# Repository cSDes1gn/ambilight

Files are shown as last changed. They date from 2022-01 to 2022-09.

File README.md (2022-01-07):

# Hyperion Server Automation



Modified: 2022-01

Hyperion
Hyperion

Ansible automation for setup and teardown of hyperion servers for raspbian lite.

## Quickstart

### Setup
Install ansible
```bash
python3 -m pip install ansible
```

Run the prelink directive passing the hostname and ip address of the pi. On rasbian the default hostname is `pi`. For example:
```bash
./scripts/prelink.sh -u pi -a 192.168.2.19
```
This essentially just adds your host systems public key to the list of authorized keys on the pi which is required to run ansible. 

>By default the script will look in `~/.ssh` for an `id_rsa.pub` file but you can pass a custom ssh keypath with the -p flag:
>```bash
>./scripts/prelink.sh -u $HOSTNAME -a $IP_ADDRESS -p $SSH_KEYPATH
>```

Create an inventory file from the example to describe automation targets:
```bash
cp inventory/example.inventory.yaml inventory/inventory.yaml
```
>Be sure to update the host and target ip.

### Automation
Run hyperion server deployment automation:
```bash
ansible-playbook main.yml -e '{ teardown: False }' -K
```

And teardown:
```bash
ansible-playbook main.yml -e '{ teardown: True }' -K
```

## License
Free to use through the [MIT License](LICENSE)

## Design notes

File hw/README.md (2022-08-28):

# Ambilight Hardware

Ambilight BOM, Power Driver and Enclosure hardware files.

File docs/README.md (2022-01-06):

# Documentation

## Access
Server hosted on
```
http://$PI_IP:8090
```

## Configuration
 - Enable Internet API Access
 - Enable capture card source

## Hyperiond
Hyperion needs to run as root to have access to the PWM interface. Probably could find a more perm solution to this but for now:
```
sudo systemctl disable --now hyperion@pi
sudo systemctl enable --now hyperion@root
```

Got locked out once:
```
sudo systemctl stop hyperion
hyperiond -v --resetPassword
sudo systemctl restart hyperion
...
```
## LED Interface
Uses WS281x PWM inteface (one wire) on GPIO18.

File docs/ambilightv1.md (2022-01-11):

# Hardware Requirements

- [ ] RPi4 Model B
- [ ] Ambilight Driver Board
- [ ] WS218B Individually Addressable LED Strip https://www.amazon.ca/gp/product/B01CDTEJBG/ref=ppx_yo_dt_b_asin_title_o05_s00?ie=UTF8&th=1
- [ ] 20A 5V PSU https://www.amazon.ca/gp/product/B07TZNMD8K/ref=ppx_yo_dt_b_asin_title_o00_s00?ie=UTF8&psc=1
- [ ] HDMI 1080p Capture Card with Linux Driver Support (No Loopback) https://www.amazon.ca/Camcorder-Definition-Acquisition-Broadcasting-Conferences/dp/B08CCYNLG4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
- [ ] 4K HDMI Splitter with HDCP 2.2 support https://www.amazon.ca/dp/B07XCZC6SP?psc=1&smid=AUHL7HYID4S97&ref_=chk_typ_imgToDp

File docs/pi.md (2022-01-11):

# Rasbian Lite Setup

1. Flash rasbian lite using the imager or whatever.

2. Enable ssh
```bash
# /Volumes/boot
touch ssh
```

3. Setup wifi
```bash
touch wpa_supplicant.conf
```

4. Setup wifi in firmware conf using wpa
```
country=US # replace with your country code
ctrl_interface=DIR=/var/run/wpa_supplicant GROUP=netdev
network={
    ssid="WIFI_NETWORK_NAME"
    psk="WIFI_PASSWORD"
    key_mgmt=WPA-PSK
}
```

## Troubleshooting
Here is the raspberrypi computer technical specification:
https://www.raspberrypi.com/documentation/computers/raspberry-pi.html#typical-power-requirements

Main issue is with power. The Pi is constantly experiencing under-voltage errors and causing eratic behaviour. The undervoltage is caused by large current draw from both the capture card and the LED strip. This has been verified using `dmesg`

Based on the RPi4B technical specification the recommended PSU current capacity is 3.0A. This is the highest amperage rating of all other RPi generations. The amperage per LED is roughly modelled by:
```
Am = n * 0.06A
```
Where n is the number of LEDs in the strip. Therefore, the max amperage for 220 LEDs is 13.2A. Factoring in the 3.0A for the pi we get 16.2A which is significantly more than the 10A supply we purchased.

Therefore there are a few options that can be done to mitigate this problem:

- [ ] Add 1000uF bulk decoupling capacitor for the LED strip\
- [ ] Add logic level inverter for PWM signal (3.3 -> 5V)
- [ ] Increase the PSU specification and add voltage regulator for pi
- [ ] Add dual USB 3.0 driver cable to support external power requirements for the capture card
- [ ] Increase the PSU specification

### Power Consumption
You can check how much power is negotiated for the 4K capture card device (`1e4e:7103`) using `lsusb`:
```
pi@raspberrypi:~ $ lsusb -v|egrep "^Bus|MaxPower"
Couldn't open device, some information will be missing
Couldn't open device, some information will be missing
Bus 002 Device 001: ID 1d6b:0003 Linux Foundation 3.0 root hub
    MaxPower                0mA
Bus 001 Device 023: ID 1e4e:7103 Cubeternet 
    MaxPower              150mA
Couldn't open device, some information will be missing
Couldn't open device, some information will be missing
Bus 001 Device 002: ID 2109:3431 VIA Labs, Inc. Hub
    MaxPower              100mA
Bus 001 Device 001: ID 1d6b:0002 Linux Foundation 2.0 root hub
    MaxPower                0mA
```

This is way below the 1.2A USB power budget for the RPi4 Model B. Therefore there is no power compatibility problem between the capture card and the RPi4.

### Capture Card UVC Driver
After some power cycles initiated by the RPi the device appears to be recognized:
```
[ 1242.891130] usb usb2-port1: attempt power cycle
[ 1247.330467] usb usb2-port1: Cannot enable. Maybe the USB cable is bad?
[ 1251.670204] usb usb2-port1: Cannot enable. Maybe the USB cable is bad?
[ 1251.670611] usb usb2-port1: unable to enumerate USB device
[ 1255.989989] usb usb2-port1: Cannot enable. Maybe the USB cable is bad?
[ 1260.529701] usb usb2-port1: Cannot enable. Maybe the USB cable is bad?
[ 1264.869483] usb usb2-port1: Cannot enable. Maybe the USB cable is bad?
[ 1264.869891] usb usb2-port1: attempt power cycle
[ 1269.309203] usb usb2-port1: Cannot enable. Maybe the USB cable is bad?
[ 1271.739284] usb 2-1: new SuperSpeed Gen 1 USB device number 52 using xhci_hcd
[ 1271.777322] usb 2-1: New USB device found, idVendor=1e4e, idProduct=7103, bcdDevice= 1.00
[ 1271.777343] usb 2-1: New USB device strings: Mfr=6, Product=7, SerialNumber=3
[ 1271.777361] usb 2-1: Product: UHA-UTCA
[ 1271.777379] usb 2-1: Manufacturer: UHA-UTCA
[ 1271.777396] usb 2-1: SerialNumber: 20000130041415
[ 1271.781874] usb 2-1: WARN: Max Exit Latency too large
[ 1271.781897] usb 2-1: Could not enable U2 link state, xHCI error -22.
[ 1271.783771] uvcvideo: Found UVC 1.00 device UHA-UTCA (1e4e:7103)
[ 1271.787861] uvcvideo: UVC non compliance - GET_DEF(PROBE) not supported. Enabling workaround.
[ 1273.758892] usb 2-1: USB disconnect, device number 52
[ 1274.109122] usb 2-1: new SuperSpeed Gen 1 USB device number 53 using xhci_hcd
[ 1274.147032] usb 2-1: New USB device found, idVendor=1e4e, idProduct=7103, bcdDevice= 1.00
[ 1274.147053] usb 2-1: New USB device strings: Mfr=6, Product=7, SerialNumber=3
[ 1274.147072] usb 2-1: Product: UHA-UTCA
[ 1274.147089] usb 2-1: Manufacturer: UHA-UTCA
[ 1274.147107] usb 2-1: SerialNumber: 20000130041415
[ 1274.149677] uvcvideo: Found UVC 1.00 device UHA-UTCA (1e4e:7103)
```

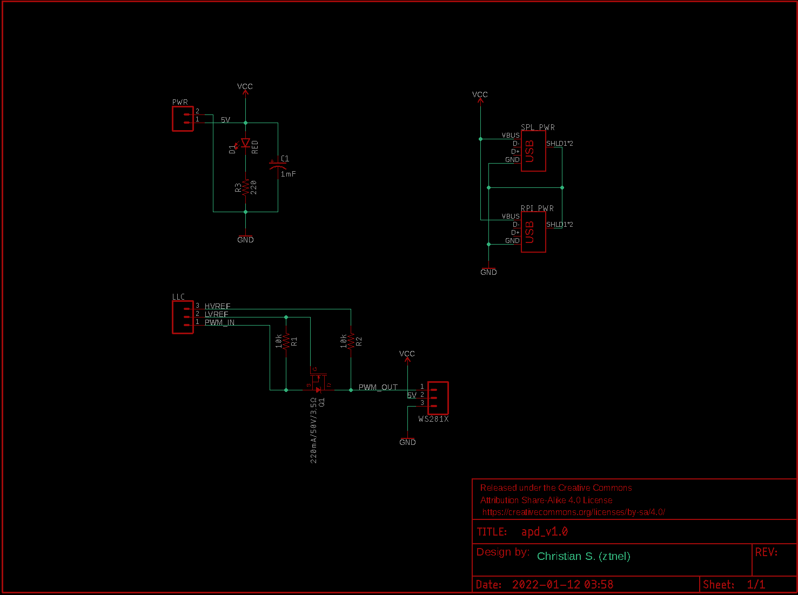
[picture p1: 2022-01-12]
hw/ambilight/apd_v1.0.png

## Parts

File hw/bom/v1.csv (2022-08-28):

Item | Manufacturer | Supplier | Quantity | Unit Price | Net Price
5m 60LEDS/m WS2812B RGB 5050SMD LED Strip | BTF-LIGHTING | Amazon | 1 | CA$50.99 | CA$50.99
5V 20A Switching PSU | Aclorol | Amazon | 1 | CA$24.39 | CA$24.39
RPi 3B/4 Zero | RaspberryPi | Amazon | 1 | CA$60.00 | CA$60.00
HDMI Capture Card USB (MS2109) | - | Amazon | 1 | CA$15.99 | CA$15.99
15A 250V Power Rocker Switch | BZ 3D | Amazon | 1 | CA$11.99 | CA$11.99
12 Pack Hook Loop Tape | EOTW | Amazon | 1 | CA$13.19 | CA$13.19
Heatshrink |  | Amazon |  |  | 0
24 AWG Wire |  | Amazon |  |  | 0
18 AWG Wire |  | Amazon |  |  | 0
2.54mm Dupont Female Crimps |  | Amazon | 5 |  | 0
2.54mm Dupont Female Covers |  | Amazon | 5 |  | 0
1mF Electrolytic Capacitor |  |  | 1 |  | 0
0603 LED |  |  | 1 |  | 0
0603 330R Resistor |  |  | 1 |  | 0
0603 10K Resistor |  |  | 2 |  | 0
BSS138 MOSFET |  | Amazon | 1 |  | 0
USB 2.0 Female SMD Connector |  | Amazon | 2 |  | 0
JST .54mm JST-XH 3 Pin Male Connectors |  | Amazon | 2 |  | 0
JST .54mm JST-XH 3 Pin Female Connectors |  | Amazon | 2 |  | 0
APDv1 PCB | JLCPCB | JLCPCB | 1 | CA$3.07 | CA$3.07
System Enclosure | - | - | 1 |  | 0
1.8mm APD Standoffs | - | - | 3 |  | 0
3.5mm RPI Standoffs | - | - | 4 |  | 0
M2 8mm Screw | PGMJ | Amazon | 3 |  | 0
M3 8mm Screw | PGMJ | Amazon | 4 |  | 0
M3 16mm Screw | PGMJ | Amazon | 3 |  | 0
 |  |  |  |  | CA$179.62

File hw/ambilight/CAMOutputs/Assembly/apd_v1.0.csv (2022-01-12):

Part | Value | Device | Package | Description | PROD_ID | SF_ID | SF_SKU | VALUE
C1 | 1mF | 1000UF-RADIAL-5MM-25V-20% | CPOL-RADIAL-5MM-10MM | 1,000µF/1mF ceramic capacitors | CAP-09538 |  |  | 1mF
D1 | RED | LED-RED0603 | LED-0603 | Red SMD LED | DIO-00819 |  |  | RED
FRAME1 | FRAME-LETTER | FRAME-LETTER | CREATIVE_COMMONS | Schematic Frame - Letter
LLC |  | CONN_03POLAR | MOLEX-1X3 | Multi connection point. Often used as Generic Header-pin footprint for 0.1 inch spaced/style header connections | CONN-08625 | PRT-08096
PWR |  | CONN_025MM | SCREWTERMINAL-5MM-2 | Multi connection point. Often used as Generic Header-pin footprint for 0.1 inch spaced/style header connections |  |  | PRT-08432
Q1 | 220mA/50V/3.5Ω | MOSFET-NCH-BSS138 | SOT23-3 | N-channel MOSFETs | TRANS-00830 |  |  | 220mA/50V/3.5Ω
R1 | 10k | 10KOHM-0603-1/10W-1% | 0603 | 10kΩ resistor | RES-00824 |  |  | 10k
R2 | 10k | 10KOHM-0603-1/10W-1% | 0603 | 10kΩ resistor | RES-00824 |  |  | 10k
R3 | 220 | 220OHM-0603-1/10W-1% | 0603 | 220Ω resistor | RES-07861 |  |  | 220
RPI_PWR | USB_A_SMT_FEMALE | USB_A_SMT_FEMALE | USB-A-S-SILK-FEMALE | USB-A Connector | CONN-09520 | PRT-09011
SPL_PWR | USB_A_SMT_FEMALE | USB_A_SMT_FEMALE | USB-A-S-SILK-FEMALE | USB-A Connector | CONN-09520 | PRT-09011
WS281X |  | CONN_03POLAR | MOLEX-1X3 | Multi connection point. Often used as Generic Header-pin footprint for 0.1 inch spaced/style header connections | CONN-08625 | PRT-08096

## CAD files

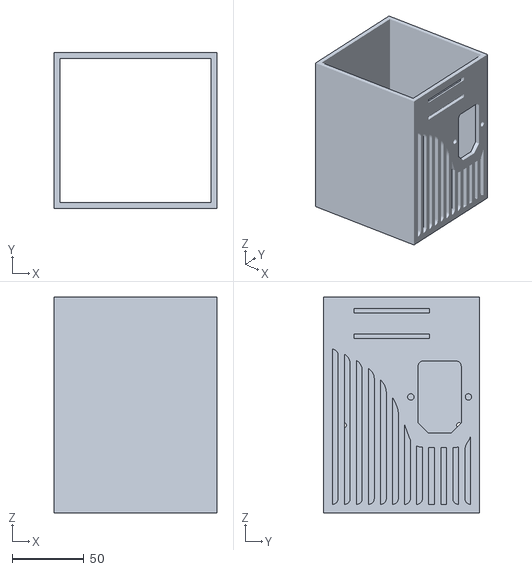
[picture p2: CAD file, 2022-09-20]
hw/fusion/Ambilight Beta v7.stl
113.0 x 108.0 x 150.0

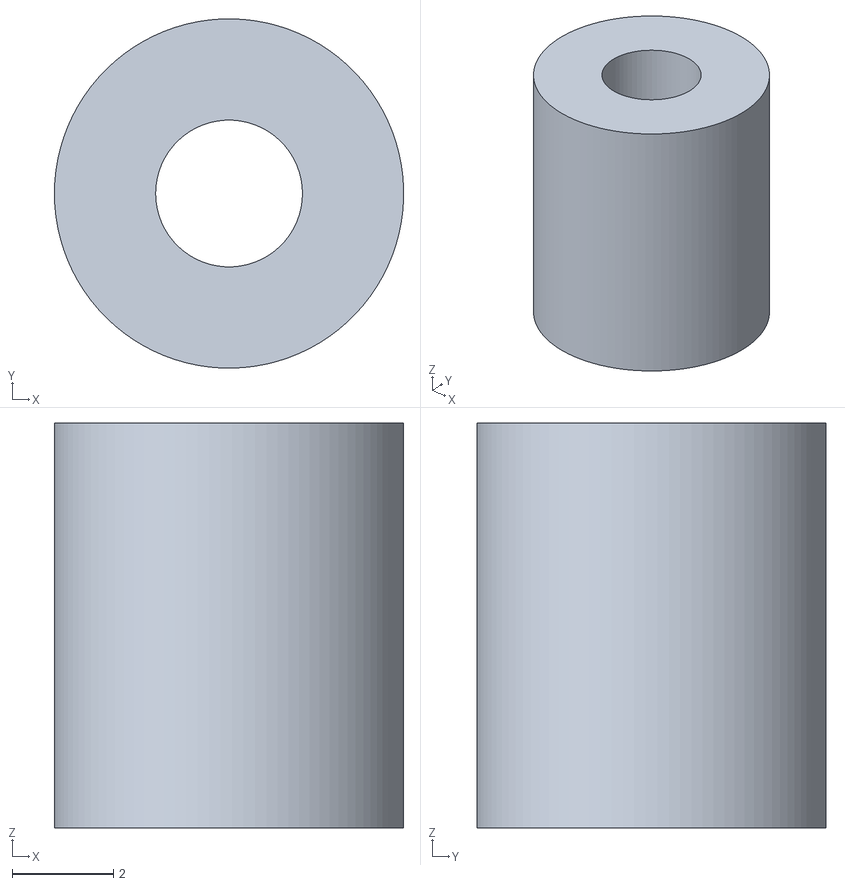
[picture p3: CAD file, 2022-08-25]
hw/fusion/rpi_standoff.stl
6.90 x 6.90 x 8.00

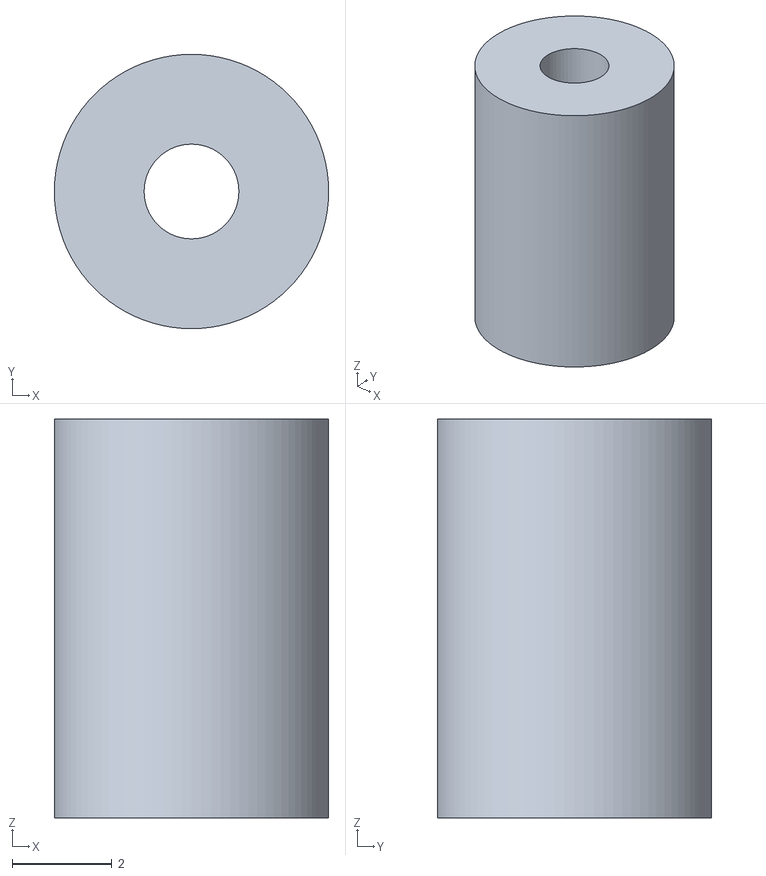
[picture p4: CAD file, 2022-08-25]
hw/fusion/apd_standoff.stl
5.50 x 5.50 x 8.00

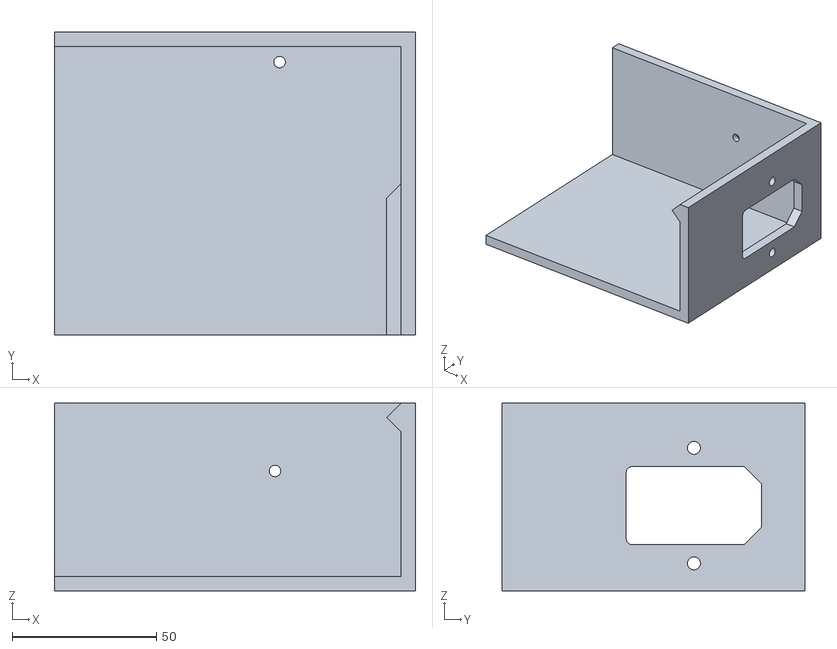
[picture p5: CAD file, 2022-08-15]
hw/fusion/Quad2.stl
125.0 x 105.0 x 65.0

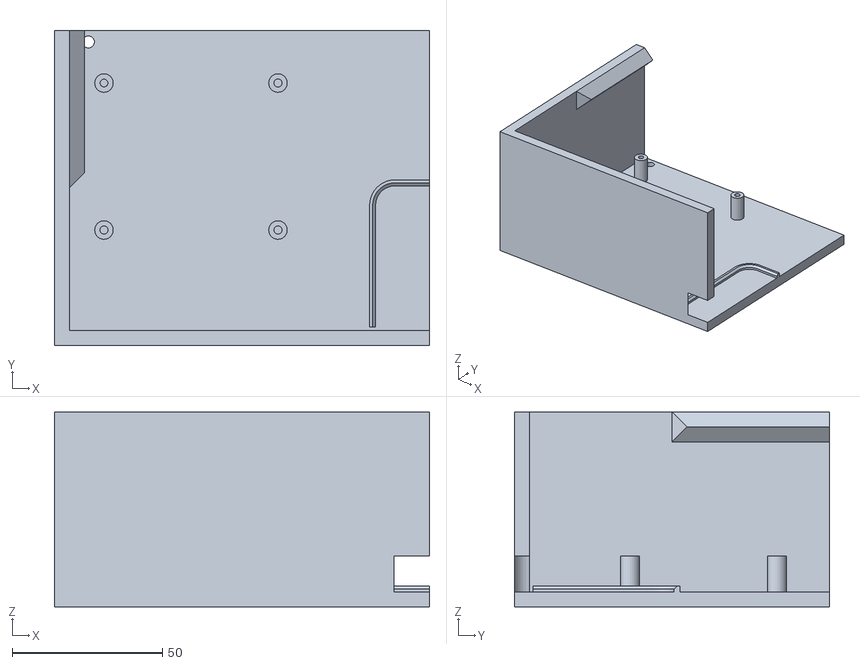
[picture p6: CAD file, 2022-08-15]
hw/fusion/Quad4.stl
125.0 x 105.0 x 65.0

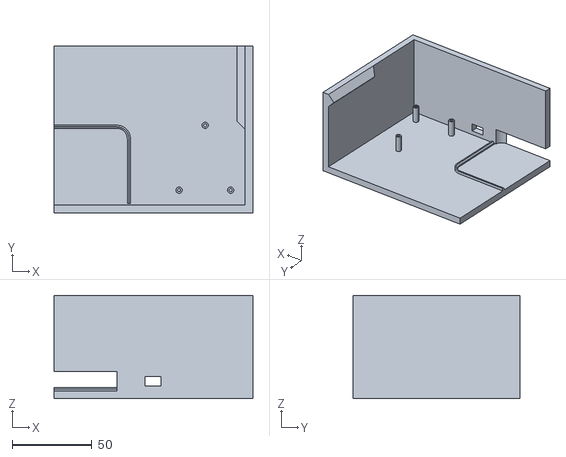
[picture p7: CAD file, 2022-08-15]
hw/fusion/Quad3.stl
125.0 x 105.0 x 65.0

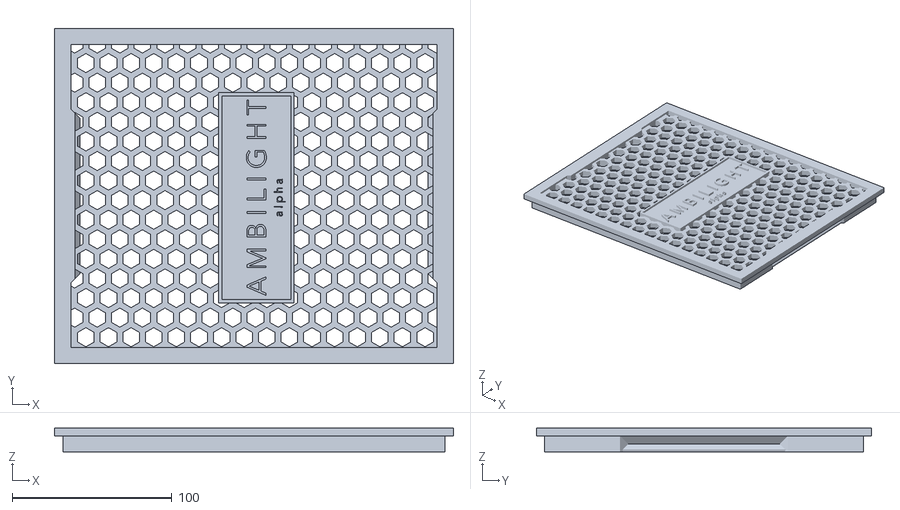
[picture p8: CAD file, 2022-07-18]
hw/fusion/Cover.stl
250.0 x 210.0 x 15.0

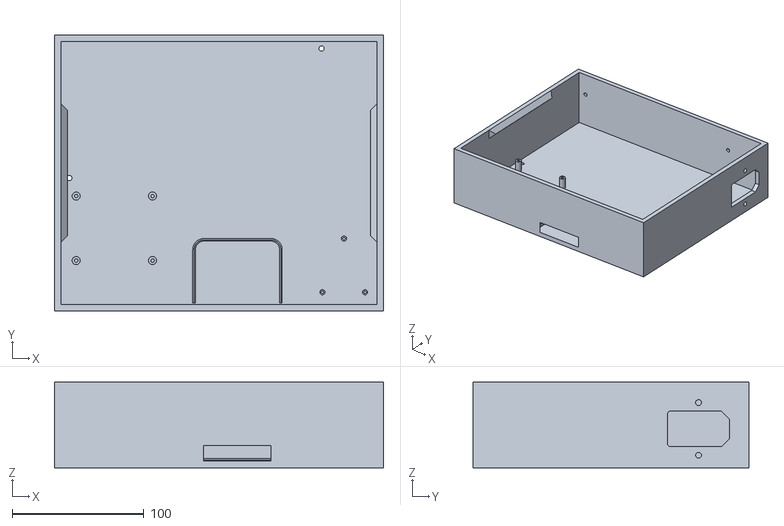
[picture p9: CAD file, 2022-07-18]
hw/fusion/Case.stl
250.0 x 210.0 x 65.0

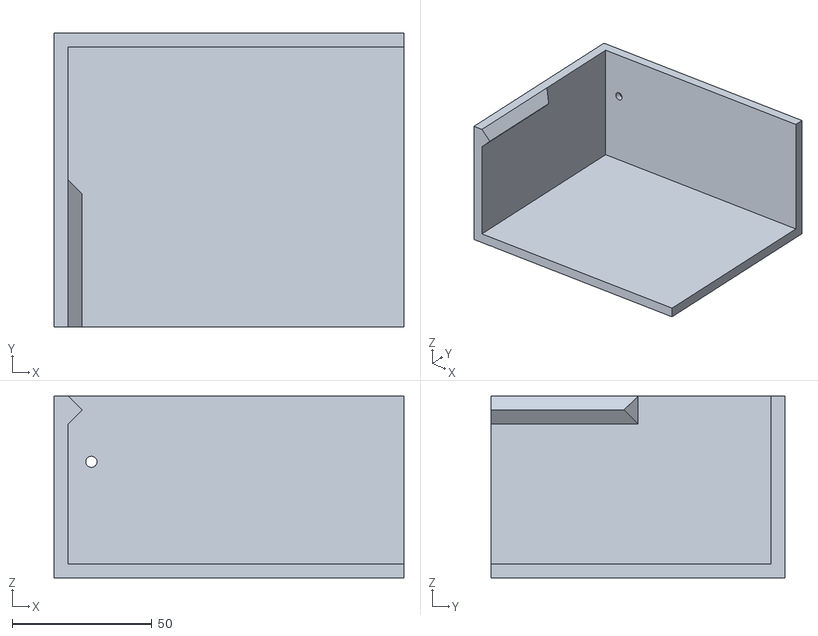
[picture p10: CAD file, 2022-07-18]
hw/fusion/Quad1.stl
125.0 x 105.0 x 65.0

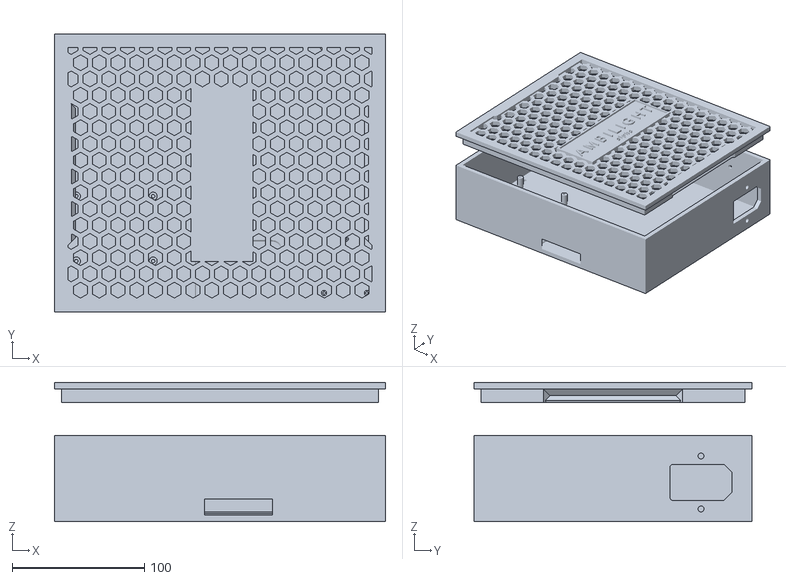
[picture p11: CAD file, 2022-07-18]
hw/fusion/Enclosure v27.stl
250.0 x 210.0 x 105.0

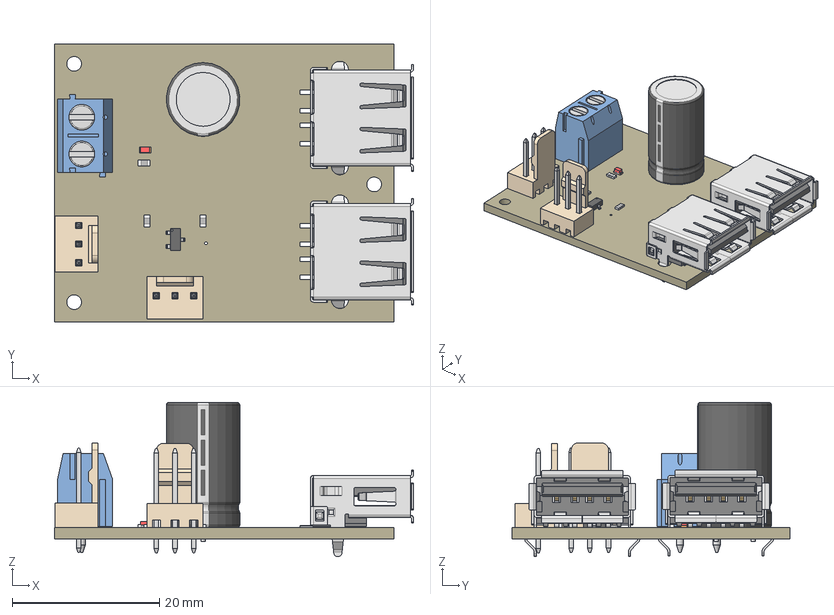
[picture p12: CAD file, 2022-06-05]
hw/fusion/apd_v1.0 v6.step
48.8 x 37.7 x 20.9 mm
Board
LED-0603
CPOL-RADIAL-5MM-10MM
6911027100xx_CAGE x 2
6911027100xx_PIN x 2
6911027100xx_VIS x 2
Shielding
Insulator
Pin x 4
Shielding (1)
Insulator (1)
Pin (1) x 4
SOT23-3
6190xx11121_PIN x 3
6190xx11121_PIN (1) x 3

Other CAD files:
hw/fusion/Ambilight Beta v6.stl
hw/fusion/Ambilight Beta v3.stl
hw/fusion/Ambilight Beta v4.stl
hw/fusion/apd_v1.0 v6.stl

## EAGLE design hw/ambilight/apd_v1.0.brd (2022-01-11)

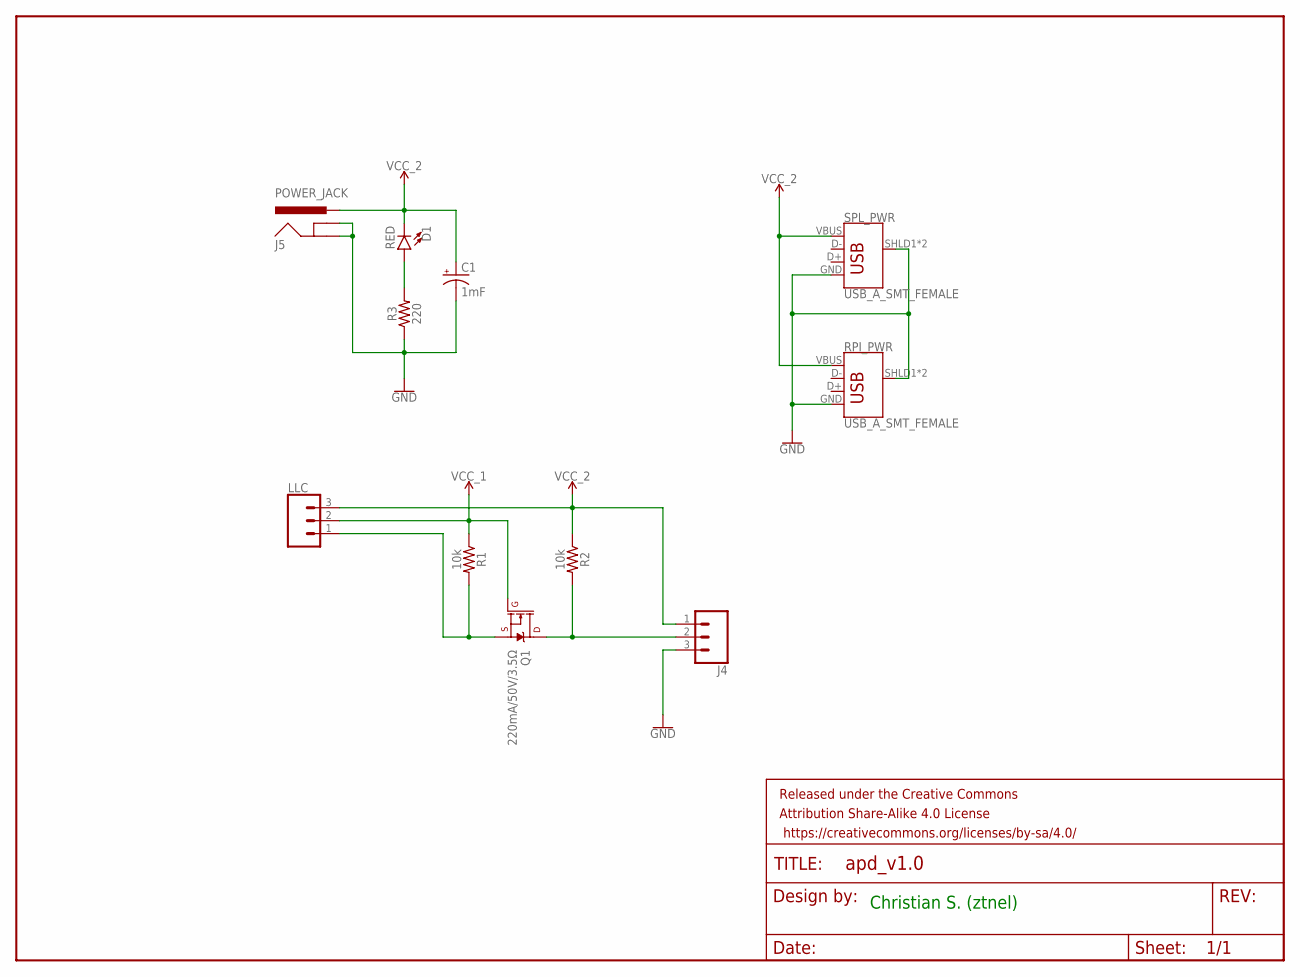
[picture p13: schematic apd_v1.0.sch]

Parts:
C1: 1mF; CPOL-RADIAL-5MM-10MM
D1: RED; LED-0603
FRAME1: FRAME-LETTER; CREATIVE_COMMONS
J4: CONN_03JST-PTH-VERT; JST-3-PTH-VERT
J5: POWER_JACK; POWER_JACK_PTH
LLC: CONN_03; 1X03
Q1: 220mA/50V/3.5Ω; SOT23-3
R1, R2: 10k; 0603
R3: 220; 0603
RPI_PWR: USB_A_SMT_FEMALE; USB-A-S-SILK-FEMALE
SPL_PWR: USB_A_SMT_FEMALE; USB-A-S-SILK-FEMALE

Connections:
GND: C1.-, J4.3, J5.GND, J5.GNDBREAK, R3.1, RPI_PWR.GND, RPI_PWR.SHLD1 (SHIELD), RPI_PWR.SHLD2 (SHIELD), SPL_PWR.GND, SPL_PWR.SHLD1 (SHIELD), SPL_PWR.SHLD2 (SHIELD)
unnamed: LLC.1, Q1.2 (S), R1.2
unnamed: J4.2, Q1.3 (D), R2.2
unnamed: D1.A, R3.2
VCC_1: LLC.2, Q1.1 (G), R1.1
VCC_2: C1.+, D1.C, J4.1, J5.PWR, LLC.3, R2.1, RPI_PWR.VBUS, SPL_PWR.VBUS

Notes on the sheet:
Christian S. (ztnel)

Board: 2 copper layers, 12 parts (0 on the bottom side), 6 nets, no tracks yet.

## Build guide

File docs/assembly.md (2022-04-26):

# Assembly Guide

> This document is a work in progress

## Power Supply Hookup

AC wall plugs have 3 prongs:
1. Live (Black) - small prong
2. Neutral (White) - wider prong
3. Earth (Green) - bottom prong

The internal wire colors for each are noted above. Typically on PSUs the inputs for the wall socket will be labelled with L for live, N for neutral and an earth ground symbol for earth.

## Wire
I am using 24 AWG wire which is rated for a maximum current carrying capacity of 14.3 A which should be the upper limit of current draw for the LEDs on the strip. If the strip is carrying more than 200 LEDs then a higher gauge wire will be required. 

## Connectors
The APD board use standard JST connectors. The LED strips you buy off amazon do not use standard JST connectors so the ends will need to be recrimped. In addition the connector driving the Logic Level Converter will need to be crimped with a JST on the side of the APD and dupont connectors on the side of the RPI GPIO

https://www.youtube.com/watch?v=l0rAEPJoWeE
https://www.youtube.com/watch?v=jET1QTP1B7c&t=255s

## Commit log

2022-01-06 add sample inventory
2022-01-11 power analysis
2022-01-11 apd rev 1
    [apd_v1.0.sch]
2022-01-12 completed v1.0 driver
    [apd_v1.0.csv, apd_v1.0.sch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]
2022-01-12 zipped gerber files
2022-04-26 assembly notes
2022-06-05 fusion exports
    [apd_v1.0 v6.step, apd_v1.0 v6.stl]
2022-07-18 fusion updates
    [Case.stl, Cover.stl, Enclosure v27.stl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]
2022-08-15 stashing v1 enclosure stls
    [Quad2.stl, Quad3.stl, Quad4.stl]
2022-08-21 new stls
    [Ambilight Beta v3.stl, Ambilight Beta v4.stl]
2022-08-25 standoffs for pi and apd
    [apd_standoff.stl, rpi_standoff.stl]
2022-08-28 add bom
    [v1.csv]
2022-08-28 update bom formatting
    [v1.csv]
2022-08-28 update bom
    [v1.csv]
2022-09-20 update beta enclosure
    [Ambilight Beta v6.stl, Ambilight Beta v7.stl]

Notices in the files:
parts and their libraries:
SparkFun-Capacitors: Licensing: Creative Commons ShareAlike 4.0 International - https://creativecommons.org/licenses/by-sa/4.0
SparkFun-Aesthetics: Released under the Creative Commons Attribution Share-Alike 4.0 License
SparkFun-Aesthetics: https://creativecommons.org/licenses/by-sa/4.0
